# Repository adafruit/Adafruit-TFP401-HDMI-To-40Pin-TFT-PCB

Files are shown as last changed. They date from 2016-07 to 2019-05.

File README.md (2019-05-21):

## Adafruit TFP401 HDMI Decoder Breakout PCB
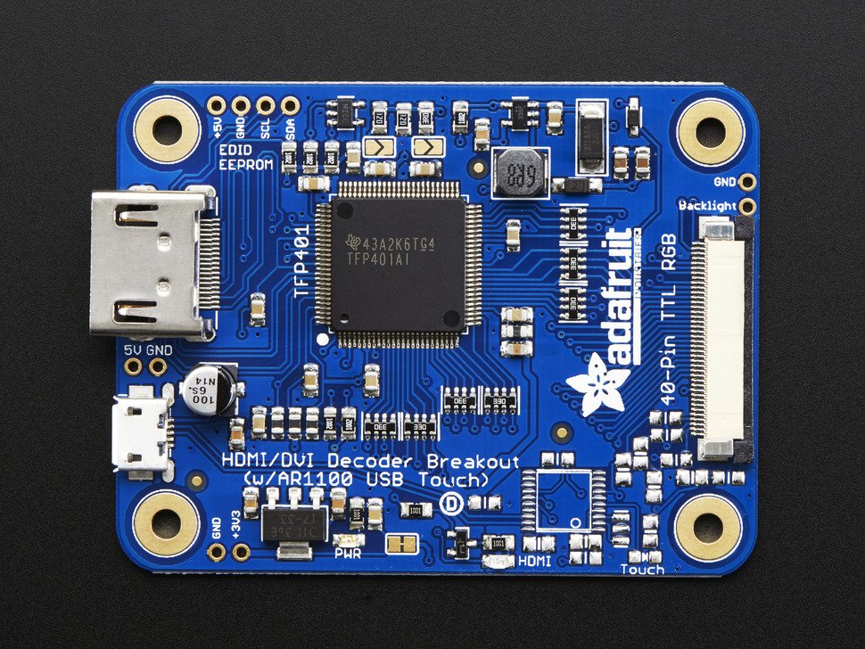
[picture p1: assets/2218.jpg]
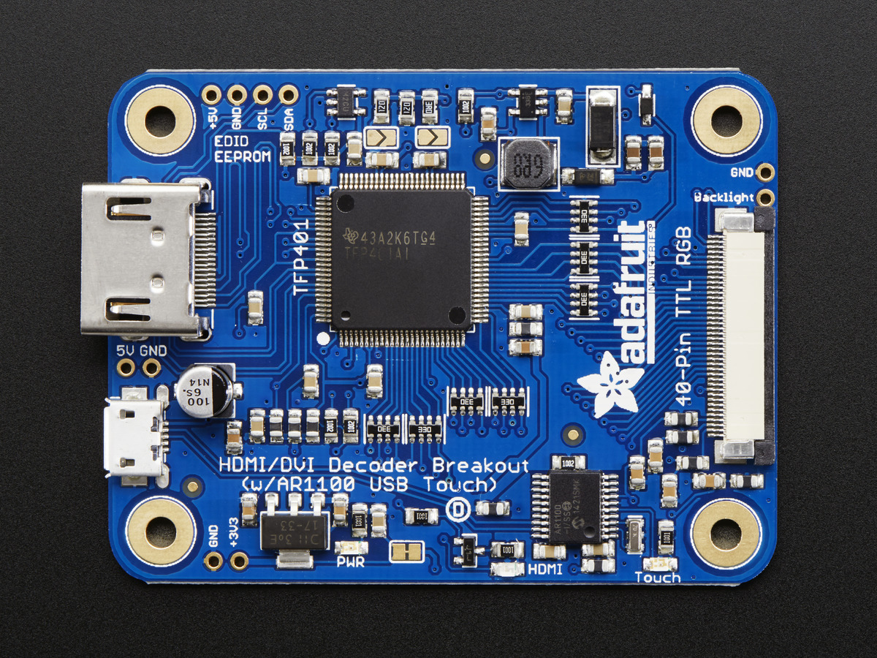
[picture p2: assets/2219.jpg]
&nbsp; <br />
Click to purchase from the Adafruit Shop:
- [TFP401 HDMI/DVI Decoder to 40-Pin TTL Breakout - Without Touch](https://www.adafruit.com/product/2218)
- [TFP401 HDMI/DVI Decoder to 40-Pin TTL Breakout - With Touch](https://www.adafruit.com/product/2219)

It's a mini HDMI decoder board! So small and simple, you can use this board as an all-in-one display driver for TTL displays, or perhaps decoding HDMI/DVI video for some other project. This breakout features the TFP401 for decoding video, and for the touch version, an AR1100 USB resistive touch screen driver.

The TFP401 is a beefy DVI/HDMI decoder from TI. It can take unencrypted video and pipe out the raw 24-bit color pixel data - HDCP not supported! It will decode any resolution from 25-165MHz pixel clock, basically up to 1080p. We've used this breakout with 800x480 displays, so we have not specifically tested it with higher resolutions. We added a bunch of supporting circuitry like a backlight driver and configured it for running basic TTL display panels such as the ones we have in the shop

There are two versions, one is video only and one is video+touch. 

PCB Files for the Adafruit TFP401 HDMI Decoder Breakout. The format is EagleCAD schematic and board layout

For more details, check out the product pages at
- http://www.adafruit.com/products/2218
- http://www.adafruit.com/products/2219

### License

Adafruit invests time and resources providing this open source design, please support Adafruit and open-source hardware by [purchasing products from Adafruit](https://www.adafruit.com)!

All text above must be included in any redistribution

Designed by Limor Fried/Ladyada for Adafruit Industries.
Creative Commons Attribution/Share-Alike, all text above must be included in any redistribution. 
See license.txt for additional information.

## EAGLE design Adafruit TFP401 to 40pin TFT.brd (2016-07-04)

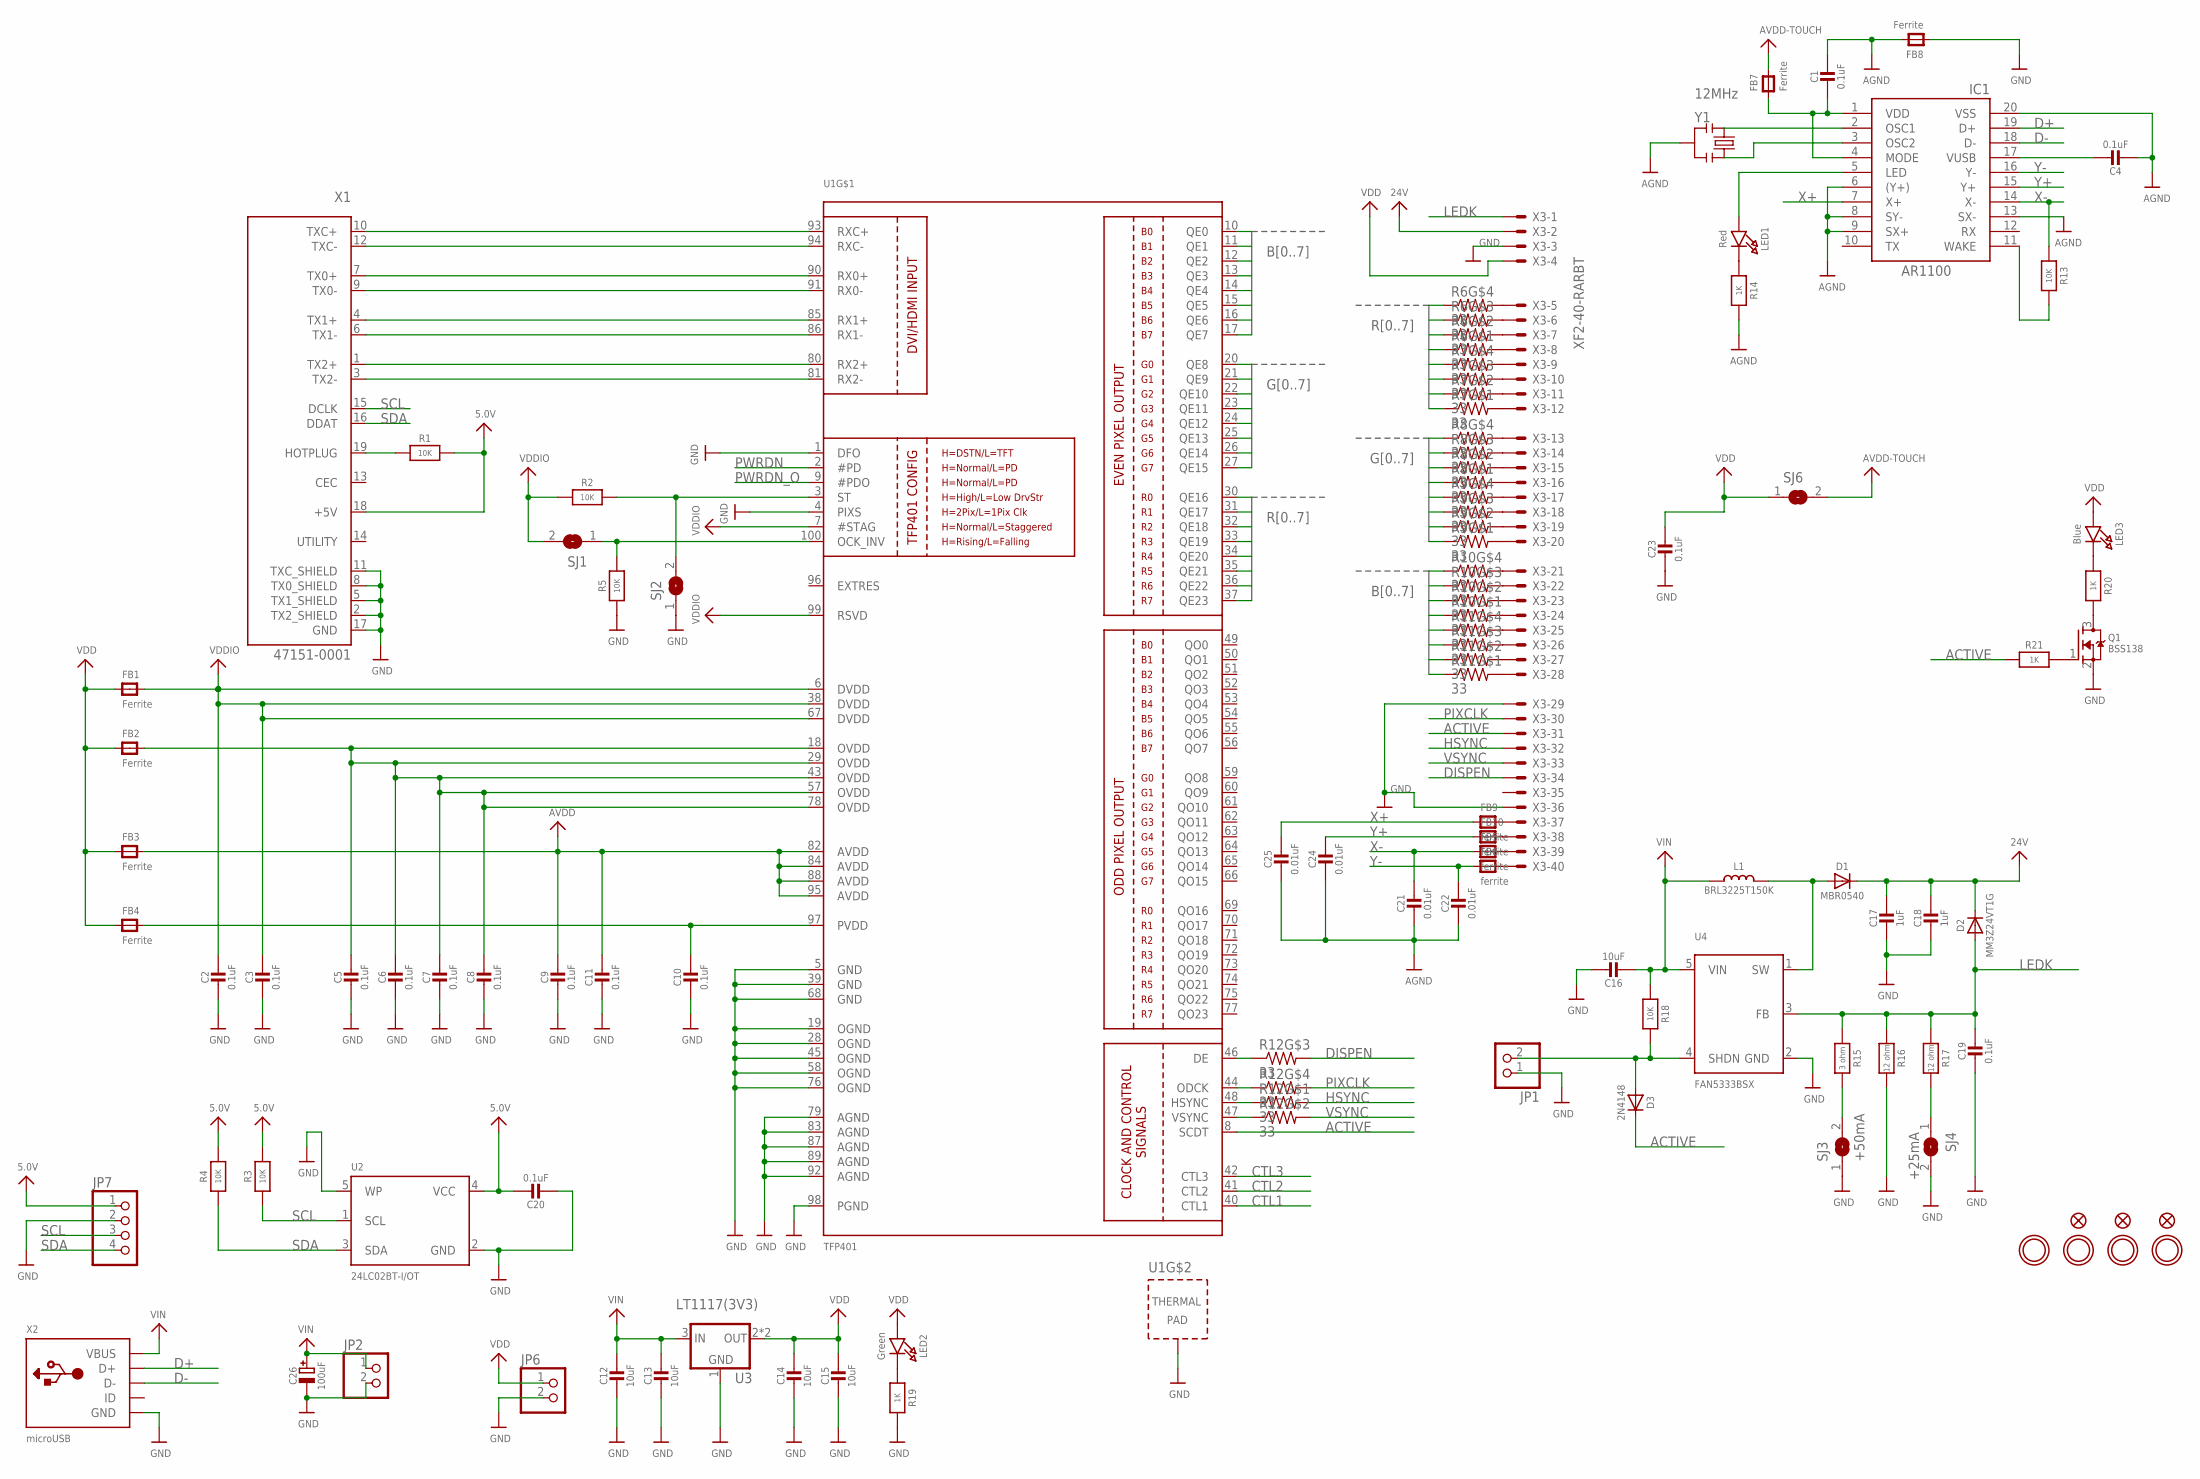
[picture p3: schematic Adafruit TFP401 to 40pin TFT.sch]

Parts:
C1, C2, C3, C4, C5, C7, C8, C9, C10, C11, C19, C20, C23: 0.1uF; 0805-NO
C6: 0.1uF; _0805MP
C12, C13, C14, C15, C16: 10uF; 0805-NO
C17, C18: 1uF; 0805-NO
C21, C22, C24, C25: 0.01uF; 0805-NO
C26: 100uF; PANASONIC_C
D1: MBR0540; SOD-123
D2: MM3Z24VT1G; SMADIODE
D3: 2N4148; SOD-323
FB1, FB2, FB3, FB4, FB7, FB8: Ferrite; _0805MP
FB5, FB6, FB9, FB10: ferrite; _0805MP
FID1, FID2, FID3: FIDUCIAL""; FIDUCIAL_1MM
IC1: AR1100_SSOP; TSSOP20-5.3MMBODY
JP1, JP2, JP6: HEADER-1X2ROUND; 1X02_ROUND
JP7: HEADER-1X476MIL; 1X04_ROUND_76
L1: BRL3225T150K; INDUCTOR_5X5MM_NR5040_NOTHERMALS
LED1: Red; CHIPLED_0805_NOOUTLINE
LED2: Green; CHIPLED_0805_NOOUTLINE
LED3: Blue; CHIPLED_0805_NOOUTLINE
Q1: BSS138; SOT23-R
R1, R2, R3, R4, R18: 10K; 0805-NO
R5, R13: 10K; _0805MP
R6, R7, R8, R9, R10, R11, R12: 33; RESPACK_4X0603
R14, R19, R20, R21: 1K; 0805-NO
R15: 3 ohm; 0805-NO
R16, R17: 12 ohm; 0805-NO
SJ1, SJ2: SOLDERJUMPER; SOLDERJUMPER_ARROW_NOPASTE
SJ3: +50mA; SOLDERJUMPER_ARROW_NOPASTE
SJ4: +25mA; SOLDERJUMPER_ARROW_NOPASTE
SJ6: SOLDERJUMPERCLOSED; SOLDERJUMPER_CLOSEDWIRE
U1: TFP401; S-PQFP-G100
U2: 24LC02BT-I/OT; SOT23-5
U3: LT1117(3V3); SOT223-R
U4: FAN5333BSX; SOT23-5
U$31, U$32, U$33, U$34: MOUNTINGHOLE3.0; MOUNTINGHOLE_3.0_PLATED
X1: 47151-0001; HDMI_MOLEX_47151-0001_DIMLAYER
X2: microUSB; 4UCONN_20329
X3: XF2-40-RARBT; 4-1734839-0
Y1: 12MHz; RESONATOR-SMD

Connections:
5.0V: C20.1, JP7.1, R1.2, R3.2, R4.2, U2.4 (VCC), X1.18 (+5V)
24V: C17.1, C18.1, D1.C, D2.C, X3.2 (MS)
ACTIVE: D3.C, R21.1, U1.8 (SCDT), X3.31 (MS)
AGND: C1.1, C4.2, C21.2, C22.2, C24.2, C25.2, FB8.2, IC1.6 ((Y+)), IC1.8 (SY-), IC1.9 (SX+), IC1.13 (SX-), IC1.20 (VSS), R14.2, Y1.2
ASD: R12.3 (1), U1.46 (DE)
AVDD: C9.1, C11.1, FB3.2, U1.82 (AVDD), U1.84 (AVDD), U1.88 (AVDD), U1.95 (AVDD)
AVDD2: FB7.2, SJ6.2
B0: R10.4 (1), U1.10 (QE0)
B1: R10.3 (1), U1.11 (QE1)
B2: R10.2 (1), U1.12 (QE2)
B3: R10.1, U1.13 (QE3)
B4: R11.4 (1), U1.14 (QE4)
B5: R11.3 (1), U1.15 (QE5)
B6: R11.2 (1), U1.16 (QE6)
B7: R11.1, U1.17 (QE7)
CTL1: U1.40 (CTL1)
CTL2: U1.41 (CTL2)
CTL3: U1.42 (CTL3)
CVB: R12.2 (1), U1.47 (VSYNC)
D+: IC1.19 (D+), X2.D+
D-: IC1.18 (D-), X2.D-
DISPEN: R12.6 (2), X3.34 (MS)
G0: R8.4 (1), U1.20 (QE8)
G1: R8.3 (1), U1.21 (QE9)
G2: R8.2 (1), U1.22 (QE10)
G3: R8.1, U1.23 (QE11)
G4: R9.4 (1), U1.24 (QE12)
G5: R9.3 (1), U1.25 (QE13)
G6: R9.2 (1), U1.26 (QE14)
G7: R9.1, U1.27 (QE15)
GND: C2.2, C3.2, C5.2, C6.2, C7.2, C8.2, C9.2, C10.2, C11.2, C12.2, C13.2, C14.2, C15.2, C16.1, C17.2, C18.2, C19.2, C20.2, C23.2, C26.-, FB8.1, JP1.1, JP2.2, JP6.2, JP7.2, Q1.2 (S), R5.1, R16.2, R19.2, SJ2.1, SJ3.1, SJ4.2, U1.1 (DFO), U1.4 (PIXS), U1.5 (GND), U1.19 (OGND), U1.28 (OGND), U1.39 (GND), U1.45 (OGND), U1.58 (OGND), U1.68 (GND), U1.76 (OGND), U1.79 (AGND), U1.83 (AGND), U1.87 (AGND), U1.89 (AGND), U1.92 (AGND), U1.98 (PGND), U1.P$1 (TP), U1.P$2 (TP), U1.P$3 (TP), U1.P$4 (TP), U1.P$5 (TP), U1.P$6 (TP), U1.P$7 (TP), U1.P$8 (TP), U1.P$9 (TP), U1.P$10 (TP), U1.P$11 (TP), U1.P$12 (TP), U1.P$13 (TP), U1.P$14 (TP), U1.P$15 (TP), U1.P$16 (TP), U1.THERMAL (TP), U2.2 (GND), U2.5 (WP), U3.1 (GND), U4.2 (GND), X1.2 (TX2_SHIELD), X1.5 (TX1_SHIELD), X1.8 (TX0_SHIELD), X1.11 (TXC_SHIELD), X1.17 (GND), X1.P$1 (GND), X1.P$2 (GND), X1.P$3 (GND), X1.P$4 (GND), X2.BASE@1 (GND), X2.BASE@2 (GND), X2.GND, X2.SPRT@1 (GND), X2.SPRT@2 (GND), X2.SPRT@3 (GND), X2.SPRT@4 (GND), X3.3 (MS), X3.29 (MS), X3.36 (MS)
HSYNC: R12.8 (2), X3.32 (MS)
LEDK: C19.1, D2.A, R15.1, R16.1, R17.1, U4.3 (FB), X3.1 (MSV)
unnamed: U1.93 (RXC+), X1.10 (TXC+)
unnamed: U1.94 (RXC-), X1.12 (TXC-)
unnamed: U1.90 (RX0+), X1.7 (TX0+)
unnamed: U1.91 (RX0-), X1.9 (TX0-)
unnamed: U1.85 (RX1+), X1.4 (TX1+)
unnamed: U1.86 (RX1-), X1.6 (TX1-)
unnamed: U1.80 (RX2+), X1.1 (TX2+)
unnamed: U1.81 (RX2-), X1.3 (TX2-)
unnamed: R1.1, X1.19 (HOTPLUG)
unnamed: IC1.2 (OSC1), Y1.1
unnamed: IC1.3 (OSC2), Y1.3
unnamed: C4.1, IC1.17 (VUSB)
unnamed: LED2.C, R19.1
unnamed: R6.5 (2), X3.5 (MS)
unnamed: R6.6 (2), X3.6 (MS)
unnamed: R6.7 (2), X3.7 (MS)
unnamed: R6.8 (2), X3.8 (MS)
unnamed: R7.5 (2), X3.9 (MS)
unnamed: R7.6 (2), X3.10 (MS)
unnamed: R7.7 (2), X3.11 (MS)
unnamed: R7.8 (2), X3.12 (MS)
unnamed: R8.5 (2), X3.13 (MS)
unnamed: R8.6 (2), X3.14 (MS)
unnamed: R8.7 (2), X3.15 (MS)
unnamed: R8.8 (2), X3.16 (MS)
unnamed: R9.5 (2), X3.17 (MS)
unnamed: R9.6 (2), X3.18 (MS)
unnamed: R9.7 (2), X3.19 (MS)
unnamed: R9.8 (2), X3.20 (MS)
unnamed: R10.5 (2), X3.21 (MS)
unnamed: R10.6 (2), X3.22 (MS)
unnamed: R10.7 (2), X3.23 (MS)
unnamed: R10.8 (2), X3.24 (MS)
unnamed: R11.5 (2), X3.25 (MS)
unnamed: R11.6 (2), X3.26 (MS)
unnamed: R11.7 (2), X3.27 (MS)
unnamed: C10.1, FB4.2, U1.97 (PVDD)
unnamed: R11.8 (2), X3.28 (MS)
unnamed: IC1.11 (WAKE), R13.2
unnamed: LED1.C, R14.1
unnamed: C5.1, C6.1, C7.1, C8.1, FB2.2, U1.18 (OVDD), U1.29 (OVDD), U1.43 (OVDD), U1.57 (OVDD), U1.78 (OVDD)
unnamed: IC1.5 (LED), LED1.A
unnamed: LED3.C, R20.1
unnamed: Q1.3 (D), R20.2
unnamed: D1.A, L1.P$2 (2), U4.1 (SW)
unnamed: Q1.1 (G), R21.2
unnamed: R15.2, SJ3.2
unnamed: R17.2, SJ4.1
unnamed: D3.A, JP1.2, R18.2, U4.4 (SHDN)
unnamed: FB5.2, X3.39 (MS)
unnamed: FB6.2, X3.40 (MS)
unnamed: C1.2, FB7.1, IC1.1 (VDD), IC1.4 (MODE)
unnamed: FB9.2, X3.37 (MS)
unnamed: FB10.2, X3.38 (MS)
OCK_INV: R5.2, SJ1.1, U1.100 (OCK_INV)
PIXCLK: R12.5 (2), X3.30 (MS)
PWRDN: U1.2 (#PD)
PWRDN_O: U1.9 (#PDO)
R0: R6.4 (1), U1.30 (QE16)
R1: R6.3 (1), U1.31 (QE17)
R2: R6.2 (1), U1.32 (QE18)
R3: R6.1, U1.33 (QE19)
R4: R7.4 (1), U1.34 (QE20)
R5: R7.3 (1), U1.35 (QE21)
R6: R7.2 (1), U1.36 (QE22)
R7: R7.1, U1.37 (QE23)
SCL: JP7.3, R3.1, U2.1 (SCL), X1.15 (DCLK)
SDA: JP7.4, R4.1, U2.3 (SDA), X1.16 (DDAT)
ST: R2.2, SJ2.2, U1.3 (ST)
VDD: C14.1, C15.1, C23.1, FB1.1, FB2.1, FB3.1, FB4.1, JP6.1, LED2.A, LED3.A, SJ6.1, U3.2 (OUT), U3.4 (OUT), X3.4 (MS)
VDDIO: C2.1, C3.1, FB1.2, R2.1, SJ1.2, U1.6 (DVDD), U1.7 (#STAG), U1.38 (DVDD), U1.67 (DVDD), U1.99 (RSVD)
VIN: C12.1, C13.1, C16.2, C26.+, JP2.1, L1.P$1 (1), R18.1, U3.3 (IN), U4.5 (VIN), X2.VBUS
VSYNC: R12.7 (2), X3.33 (MS)
X+: C25.1, FB9.1, IC1.7 (X+)
X-: C21.1, FB5.1, IC1.14 (X-), R13.1
XCV: R12.1, U1.48 (HSYNC)
Y+: C24.1, FB10.1, IC1.15 (Y+)
Y-: C22.1, FB6.1, IC1.16 (Y-)
ZXC: R12.4 (1), U1.44 (ODCK)

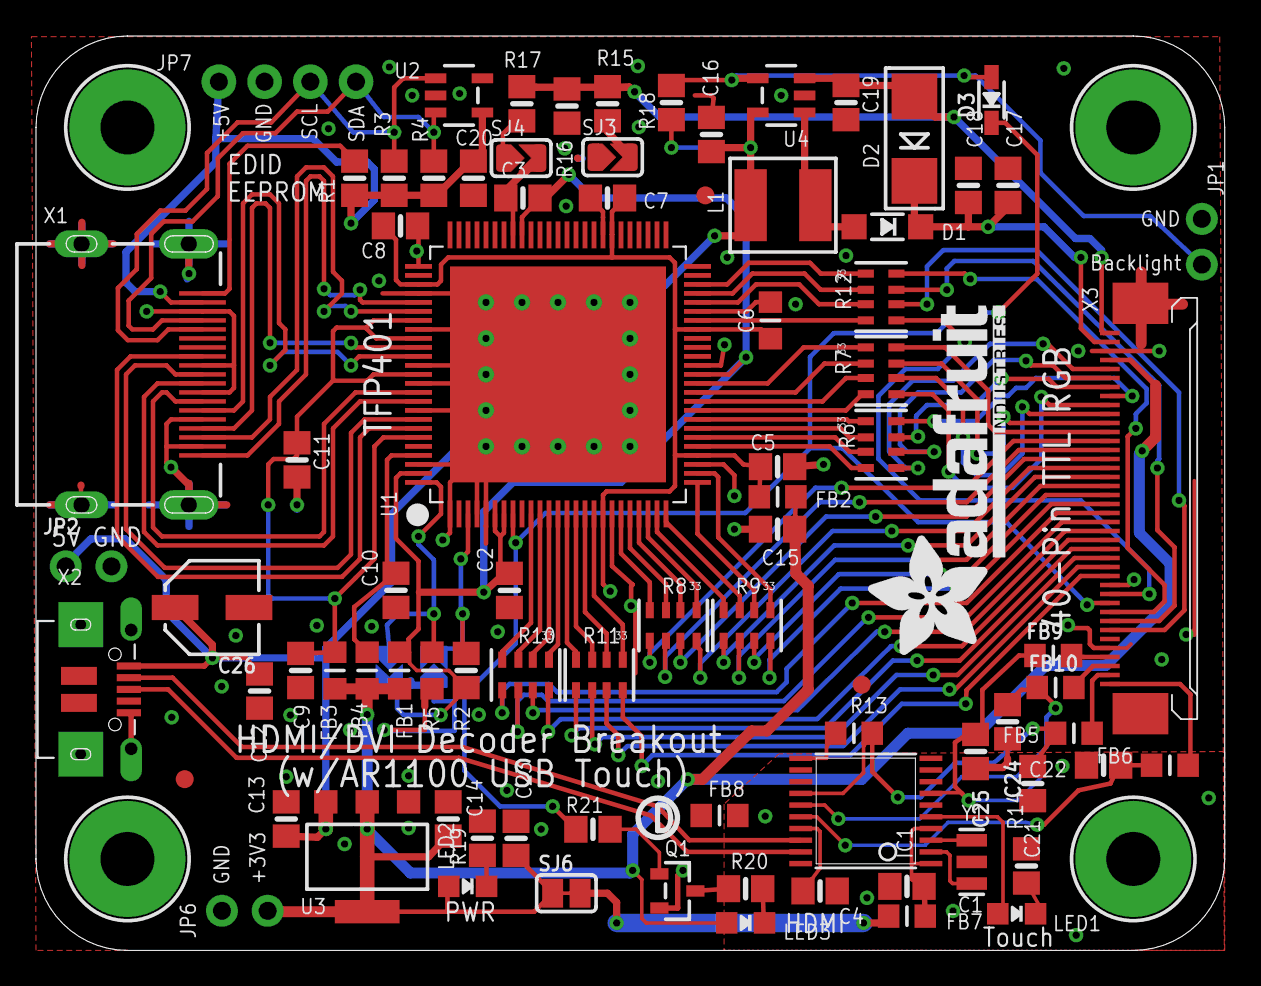
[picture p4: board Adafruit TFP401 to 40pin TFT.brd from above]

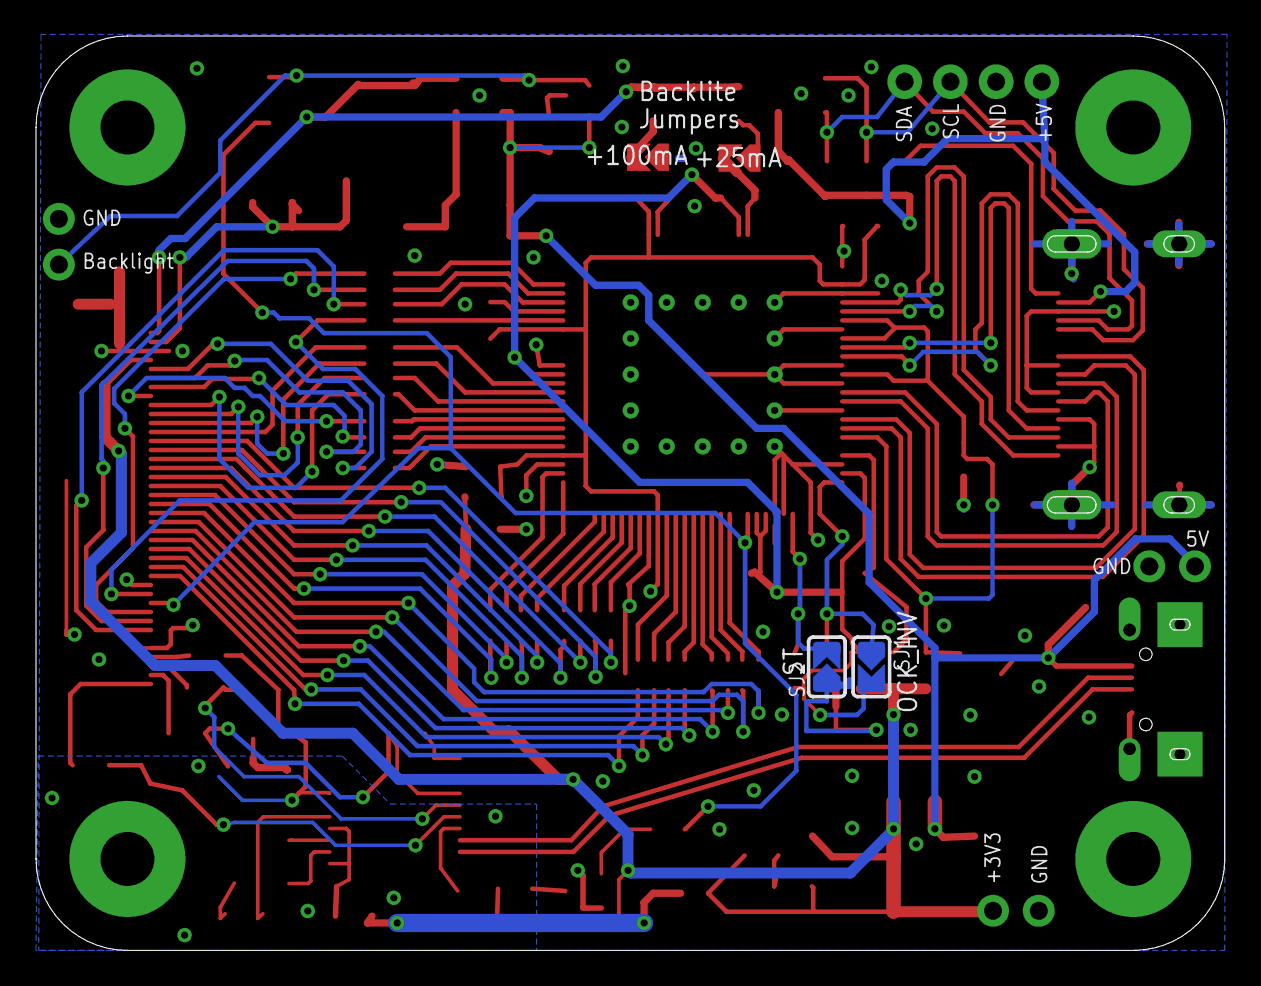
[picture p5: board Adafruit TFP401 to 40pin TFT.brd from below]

Board: 2 copper layers, 66.0 x 50.8 mm, 92 parts (2 on the bottom side), 107 nets.

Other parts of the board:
U$80: PCBFEAT-REV-056
U$81: ADAFRUIT_TEXT_20MM

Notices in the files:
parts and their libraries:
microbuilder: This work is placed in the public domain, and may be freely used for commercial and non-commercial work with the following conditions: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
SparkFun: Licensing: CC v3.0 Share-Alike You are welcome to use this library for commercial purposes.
